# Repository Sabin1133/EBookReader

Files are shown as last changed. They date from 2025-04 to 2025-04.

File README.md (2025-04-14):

###### Copyright Sabin Padurariu 2025

# OpenBook E-Reader

## General Overview

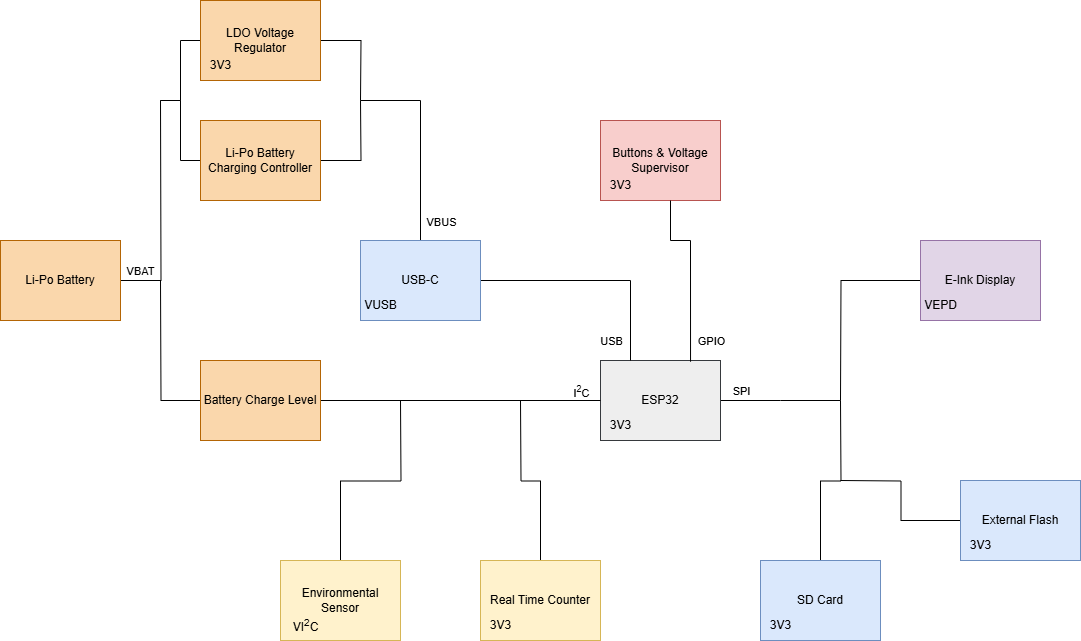
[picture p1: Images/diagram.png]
diagram


OpenBook is a compact electronic device designed around the ESP32 microcontroller. This device integrates several key features, including:

* Li-Po battery charging and power management
* E-Paper display for visual output
* Environmental sensing capabilities with the BME688 sensor
* Real-Time Clock (RTC) functionality using the DS3231SN
* SD Card slot for data storage
* External NOR Flash memory
* USB-C connectivity

## Bill of Materials

| Name | Price Link | Datasheet Link |
|---|---|---|
|	BOOT_BUTTON	|	https://www.snapeda.com/parts/EVQP7L01P/Panasonic/view-part/?welcome=home&ref=search&t=evqp7l01p	|	https://industry.panasonic.com/global/en/downloads?tab=catalog&small_g_cd=203&part_no=EVQPUJ02K	|
|	C1	|	https://componentsearchengine.com/part-view/CC0402MRX5R5BB106/YAGEO	|	https://componentsearchengine.com/Datasheets/2/CC0402MRX5R5BB106.pdf	|
|	C1_BAT	|	https://componentsearchengine.com/part-view/CC0402MRX5R5BB106/YAGEO	|	https://componentsearchengine.com/Datasheets/2/CC0402MRX5R5BB106.pdf	|
|	C1_BAT1	|	https://www.snapeda.com/parts/CC0402DRNPO9BN5R1/Yageo/view-part/?ref=dk&t=LTSPICE_CC0402&con_ref=None	|	https://s3.amazonaws.com/snapeda/datasheet/CC0402DRNPO9BN5R1_Yageo.pdf	|
|	C2_BAT1	|	https://www.snapeda.com/parts/CC0402DRNPO9BN5R1/Yageo/view-part/?ref=dk&t=LTSPICE_CC0402&con_ref=None	|	https://s3.amazonaws.com/snapeda/datasheet/CC0402DRNPO9BN5R1_Yageo.pdf	|
|	C1_BAT2	| https://www.snapeda.com/parts/CC0402DRNPO9BN5R1/Yageo/view-part/?ref=dk&t=LTSPICE_CC0402&con_ref=None	|	https://s3.amazonaws.com/snapeda/datasheet/CC0402DRNPO9BN5R1_Yageo.pdf	|
|	C2	|	https://componentsearchengine.com/part-view/CC0402MRX5R5BB106/YAGEO	|	https://componentsearchengine.com/Datasheets/2/CC0402MRX5R5BB106.pdf	|
|	C2_BAT	|	https://componentsearchengine.com/part-view/CC0402MRX5R5BB106/YAGEO	|	https://componentsearchengine.com/Datasheets/2/CC0402MRX5R5BB106.pdf	|
|	C3	|	https://componentsearchengine.com/part-view/T491B107M006AT/KEMET	|	https://s3.amazonaws.com/snapeda/datasheet/TAJB475K025RNJ_AVX.pdf	|
|	C4	|	https://componentsearchengine.com/part-view/CC0402MRX5R5BB106/YAGEO	|	https://componentsearchengine.com/Datasheets/2/CC0402MRX5R5BB106.pdf	|
|	C4_USB	|	https://componentsearchengine.com/part-view/CC0402MRX5R5BB106/YAGEO	|	https://componentsearchengine.com/Datasheets/2/CC0402MRX5R5BB106.pdf	|
|	C5	|	https://componentsearchengine.com/part-view/CC0402MRX5R5BB106/YAGEO	|	https://componentsearchengine.com/Datasheets/2/CC0402MRX5R5BB106.pdf	|
|	C5_USB	|	https://componentsearchengine.com/part-view/CC0402MRX5R5BB106/YAGEO	|	https://componentsearchengine.com/Datasheets/2/CC0402MRX5R5BB106.pdf	|
|	C6	|	https://componentsearchengine.com/part-view/CC0402MRX5R5BB106/YAGEO	|	https://componentsearchengine.com/Datasheets/2/CC0402MRX5R5BB106.pdf	|
|	C7	|	https://componentsearchengine.com/part-view/CC0402MRX5R5BB106/YAGEO	|	https://componentsearchengine.com/Datasheets/2/CC0402MRX5R5BB106.pdf	|
|	C8	|	https://componentsearchengine.com/part-view/CC0402MRX5R5BB106/YAGEO	|	https://componentsearchengine.com/Datasheets/2/CC0402MRX5R5BB106.pdf	|
|	C9	|	https://www.snapeda.com/parts/CC0402DRNPO9BN5R1/Yageo/view-part/?ref=dk&t=LTSPICE_CC0402&con_ref=None	|	https://s3.amazonaws.com/snapeda/datasheet/CC0402DRNPO9BN5R1_Yageo.pdf	|
|	C10	|	https://componentsearchengine.com/part-view/CC0402MRX5R5BB106/YAGEO	|	https://componentsearchengine.com/Datasheets/2/CC0402MRX5R5BB106.pdf	|
|	C10_SUPERCAP	|	https://www.snapeda.com/parts/CPH3225A/Seiko+Instruments/view-part/?ref=eda	|	https://www.snapeda.com/parts/CPH3225A/Seiko%20Instruments/datasheet/	|
|	CHANGE_BUTTON	|	https://www.snapeda.com/parts/EVQP7L01P/Panasonic/view-part/?welcome=home&ref=search&t=evqp7l01p	|	https://industry.panasonic.com/global/en/downloads?tab=catalog&small_g_cd=203&part_no=EVQPUJ02K	|
|	CHG_LED	|	https://www.snapeda.com/parts/KP-1608SURCK/Kingbright/view-part/?ref=search&t=LED%200603	|	https://www.snapeda.com/parts/KP-1608SURCK/Kingbright/datasheet/	|
|	C_DELAY	|	https://componentsearchengine.com/part-view/CC0402MRX5R5BB106/YAGEO	|	https://componentsearchengine.com/Datasheets/2/CC0402MRX5R5BB106.pdf	|
|	D1	|	https://www.snapeda.com/parts/USBLC6-2SC6Y/STMicroelectronics/view-part/?ref=snap	|	https://www.snapeda.com/parts/USBLC6-2SC6Y/STMicroelectronics/datasheet/	|
|	D2	|	https://ro.mouser.com/ProductDetail/KYOCERA-AVX/SD0805S020S1R0?qs=jCA%252BPfw4LHbpkAoSnwrdjw%3D%3D	|	http://datasheets.avx.com/schottky.pdf	|
|	D3	|	https://www.snapeda.com/parts/MBR0530/Onsemi/view-part/?ref=eda	|	https://www.snapeda.com/parts/MBR0530/ON%20Semiconductor/datasheet/	|
|	D4	|	https://www.snapeda.com/parts/MBR0530/Onsemi/view-part/?ref=eda	|	https://www.snapeda.com/parts/MBR0530/ON%20Semiconductor/datasheet/	|
|	D5	|	https://www.snapeda.com/parts/MBR0530/Onsemi/view-part/?ref=eda	|	https://www.snapeda.com/parts/MBR0530/ON%20Semiconductor/datasheet/	|
|	D6	|	https://www.snapeda.com/parts/PGB1010603MR/Littelfuse/view-part/?ref=eda	|	https://www.snapeda.com/parts/PGB1010603MR/Littelfuse%20Inc./datasheet/	|
|	D7	|	https://ro.mouser.com/ProductDetail/KYOCERA-AVX/SD0805S020S1R0?qs=jCA%252BPfw4LHbpkAoSnwrdjw%3D%3D	|	http://datasheets.avx.com/schottky.pdf	|
|	D8	|	https://www.snapeda.com/parts/PGB1010603MR/Littelfuse/view-part/?ref=eda	|	https://www.snapeda.com/parts/PGB1010603MR/Littelfuse%20Inc./datasheet/	|
|	D9	|	https://www.snapeda.com/parts/PGB1010603MR/Littelfuse/view-part/?ref=eda	|	https://www.snapeda.com/parts/PGB1010603MR/Littelfuse%20Inc./datasheet/	|
|	D10	|	https://www.snapeda.com/parts/PGB1010603MR/Littelfuse/view-part/?ref=eda	|	https://www.snapeda.com/parts/PGB1010603MR/Littelfuse%20Inc./datasheet/	|
|	D11	|	https://www.snapeda.com/parts/PGB1010603MR/Littelfuse/view-part/?ref=eda	|	https://www.snapeda.com/parts/PGB1010603MR/Littelfuse%20Inc./datasheet/	|
|	D12	|	https://www.snapeda.com/parts/PGB1010603MR/Littelfuse/view-part/?ref=eda	|	https://www.snapeda.com/parts/PGB1010603MR/Littelfuse%20Inc./datasheet/	|
|	EPD_C1	|	https://componentsearchengine.com/part-view/CC0402MRX5R5BB106/YAGEO	|	https://componentsearchengine.com/Datasheets/2/CC0402MRX5R5BB106.pdf	|
|	EPD_C2	|	https://componentsearchengine.com/part-view/CC0402MRX5R5BB106/YAGEO	|	https://componentsearchengine.com/Datasheets/2/CC0402MRX5R5BB106.pdf	|
|	EPD_C5	|	https://componentsearchengine.com/part-view/CC0402MRX5R5BB106/YAGEO	|	https://componentsearchengine.com/Datasheets/2/CC0402MRX5R5BB106.pdf	|
|	EPD_C6	|	https://componentsearchengine.com/part-view/CC0402MRX5R5BB106/YAGEO	|	https://componentsearchengine.com/Datasheets/2/CC0402MRX5R5BB106.pdf	|
|	EPD_C7	|	https://componentsearchengine.com/part-view/CC0402MRX5R5BB106/YAGEO	|	https://componentsearchengine.com/Datasheets/2/CC0402MRX5R5BB106.pdf	|
|	EPD_C8	|	https://componentsearchengine.com/part-view/CC0402MRX5R5BB106/YAGEO	|	https://componentsearchengine.com/Datasheets/2/CC0402MRX5R5BB106.pdf	|
|	EPD_C9	|	https://componentsearchengine.com/part-view/CC0402MRX5R5BB106/YAGEO	|	https://componentsearchengine.com/Datasheets/2/CC0402MRX5R5BB106.pdf	|
|	EPD_C10	|	https://componentsearchengine.com/part-view/CC0402MRX5R5BB106/YAGEO	|	https://componentsearchengine.com/Datasheets/2/CC0402MRX5R5BB106.pdf	|
|	EPD_C11	|	https://componentsearchengine.com/part-view/CC0402MRX5R5BB106/YAGEO	|	https://componentsearchengine.com/Datasheets/2/CC0402MRX5R5BB106.pdf	|
|	EPD_C12	|	https://componentsearchengine.com/part-view/CC0402MRX5R5BB106/YAGEO	|	https://componentsearchengine.com/Datasheets/2/CC0402MRX5R5BB106.pdf	|
|	IC1	|	https://componentsearchengine.com/part-view/BD5229G-TR/ROHM%20Semiconductor	|	https://datasheet.datasheetarchive.com/originals/distributors/Datasheets_SAMA/f2b9741ef86007909f138d561a359946.pdf	|
|	IC4	|	https://componentsearchengine.com/part-view/XC6220A331MR-G/Torex	|	https://product.torexsemi.com/system/files/series/xc6220.pdf	|
|	J1	|	https://componentsearchengine.com/part-view/FH34SRJ-24S-0.5SH(99)/Hirose	|	https://www.hirose.com/en/product/document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	|
|	J2	|	https://componentsearchengine.com/part-view/USB4110-GF-A/GCT%20(GLOBAL%20CONNECTOR%20TECHNOLOGY)	|	https://gct.co/files/drawings/usb4110.pdf	|
|	J3	|	https://componentsearchengine.com/part-view/SM04B-SRSS-TB(LF)(SN)/JST%20(JAPAN%20SOLDERLESS%20TERMINALS)	| - |
|	J4	|	https://store.comet.srl.ro/Catalogue/Product/43497/	|	https://store.comet.srl.ro/Catalogue/Product/43497/	|
|	L1	|	https://ro.mouser.com/ProductDetail/Wurth-Elektronik/744043680?qs=PGXP4M47uW6VkZq%252BkzjrHA%3D%3D	|	https://www.we-online.com/components/products/datasheet/744043680.pdf	|
|	PFMF.050.1	|	https://ro.mouser.com/ProductDetail/EPCOS-TDK/B72520T0350K062?qs=dEfas%2FXlABIszF52uu7vrg%3D%3D	|	https://www.mouser.co.uk/ProductDetail/EPCOS-TDK/B72520T0350K062?qs=dEfas%2FXlABIszF52uu7vrg%3D%3D	|
|	Q1	|	https://componentsearchengine.com/part-view/DMG2305UX-7/Diodes%20Incorporated	|	https://www.diodes.com//assets/Datasheets/DMG2305UX.pdf	|
|	Q2	|	https://componentsearchengine.com/part-view/DMG2305UX-7/Diodes%20Incorporated	|	https://www.diodes.com//assets/Datasheets/DMG2305UX.pdf	|
|	Q3	|	https://componentsearchengine.com/part-view/SI1308EDL-T1-GE3/Vishay	|	https://componentsearchengine.com/Datasheets/1/SI1308EDL-T1-GE3.pdf	|
|	R1	|	https://componentsearchengine.com/part-view/R0402%201%25%20100%20K%20(RC0402FR-07100KL)/YAGEO	|	https://www.yageo.com/upload/media/product/products/datasheet/rchip/PYu-RC_Group_51_RoHS_L_12.pdf	|
|	R1-PINH	|	https://componentsearchengine.com/part-view/R0402%201%25%20100%20K%20(RC0402FR-07100KL)/YAGEO	|	https://www.yageo.com/upload/media/product/products/datasheet/rchip/PYu-RC_Group_51_RoHS_L_12.pdf	|
|	R1-PINH1	|	https://componentsearchengine.com/part-view/R0402%201%25%20100%20K%20(RC0402FR-07100KL)/YAGEO	|	https://www.yageo.com/upload/media/product/products/datasheet/rchip/PYu-RC_Group_51_RoHS_L_12.pdf	|
|	R1_BAT	|	https://componentsearchengine.com/part-view/R0402%201%25%20100%20K%20(RC0402FR-07100KL)/YAGEO	|	https://www.yageo.com/upload/media/product/products/datasheet/rchip/PYu-RC_Group_51_RoHS_L_12.pdf	|
|	R1_PWRUSB	|	https://componentsearchengine.com/part-view/R0402%201%25%20100%20K%20(RC0402FR-07100KL)/YAGEO	|	https://www.yageo.com/upload/media/product/products/datasheet/rchip/PYu-RC_Group_51_RoHS_L_12.pdf	|
|	R2	|	https://componentsearchengine.com/part-view/R0402%201%25%20100%20K%20(RC0402FR-07100KL)/YAGEO	|	https://www.yageo.com/upload/media/product/products/datasheet/rchip/PYu-RC_Group_51_RoHS_L_12.pdf	|
|	R2-PINH	|	https://componentsearchengine.com/part-view/R0402%201%25%20100%20K%20(RC0402FR-07100KL)/YAGEO	|	https://www.yageo.com/upload/media/product/products/datasheet/rchip/PYu-RC_Group_51_RoHS_L_12.pdf	|
|	R2-PINH1	|	https://componentsearchengine.com/part-view/R0402%201%25%20100%20K%20(RC0402FR-07100KL)/YAGEO	|	https://www.yageo.com/upload/media/product/products/datasheet/rchip/PYu-RC_Group_51_RoHS_L_12.pdf	|
|	R2-USB	|	https://componentsearchengine.com/part-view/R0402%201%25%20100%20K%20(RC0402FR-07100KL)/YAGEO	|	https://www.yageo.com/upload/media/product/products/datasheet/rchip/PYu-RC_Group_51_RoHS_L_12.pdf	|
|	R2-USB1	|	https://componentsearchengine.com/part-view/R0402%201%25%20100%20K%20(RC0402FR-07100KL)/YAGEO	|	https://www.yageo.com/upload/media/product/products/datasheet/rchip/PYu-RC_Group_51_RoHS_L_12.pdf	|
|	R2_BAT	|	https://componentsearchengine.com/part-view/R0402%201%25%20100%20K%20(RC0402FR-07100KL)/YAGEO	|	https://www.yageo.com/upload/media/product/products/datasheet/rchip/PYu-RC_Group_51_RoHS_L_12.pdf	|
|	R3	|	https://componentsearchengine.com/part-view/R0402%201%25%20100%20K%20(RC0402FR-07100KL)/YAGEO	|	https://www.yageo.com/upload/media/product/products/datasheet/rchip/PYu-RC_Group_51_RoHS_L_12.pdf	|
|	R4	|	https://componentsearchengine.com/part-view/R0402%201%25%20100%20K%20(RC0402FR-07100KL)/YAGEO	|	https://www.yageo.com/upload/media/product/products/datasheet/rchip/PYu-RC_Group_51_RoHS_L_12.pdf	|
|	R5	|	https://componentsearchengine.com/part-view/R0402%201%25%20100%20K%20(RC0402FR-07100KL)/YAGEO	|	https://www.yageo.com/upload/media/product/products/datasheet/rchip/PYu-RC_Group_51_RoHS_L_12.pdf	|
|	R6	|	https://componentsearchengine.com/part-view/R0402%201%25%20100%20K%20(RC0402FR-07100KL)/YAGEO	|	https://www.yageo.com/upload/media/product/products/datasheet/rchip/PYu-RC_Group_51_RoHS_L_12.pdf	|
|	R7	|	https://componentsearchengine.com/part-view/R0402%201%25%20100%20K%20(RC0402FR-07100KL)/YAGEO	|	https://www.yageo.com/upload/media/product/products/datasheet/rchip/PYu-RC_Group_51_RoHS_L_12.pdf	|
|	R8	|	https://componentsearchengine.com/part-view/R0402%201%25%20100%20K%20(RC0402FR-07100KL)/YAGEO	|	https://www.yageo.com/upload/media/product/products/datasheet/rchip/PYu-RC_Group_51_RoHS_L_12.pdf	|
|	R9	|	https://componentsearchengine.com/part-view/R0402%201%25%20100%20K%20(RC0402FR-07100KL)/YAGEO	|	https://www.yageo.com/upload/media/product/products/datasheet/rchip/PYu-RC_Group_51_RoHS_L_12.pdf	|
|	R10	|	https://componentsearchengine.com/part-view/R0402%201%25%20100%20K%20(RC0402FR-07100KL)/YAGEO	|	https://www.yageo.com/upload/media/product/products/datasheet/rchip/PYu-RC_Group_51_RoHS_L_12.pdf	|
|	RESET_BUTTON	|	https://www.snapeda.com/parts/EVQP7L01P/Panasonic/view-part/?welcome=home&ref=search&t=evqp7l01p	|	https://industry.panasonic.com/global/en/downloads?tab=catalog&small_g_cd=203&part_no=EVQPUJ02K	|
|	R_BOOT	|	https://componentsearchengine.com/part-view/R0402%201%25%20100%20K%20(RC0402FR-07100KL)/YAGEO	|	https://www.yageo.com/upload/media/product/products/datasheet/rchip/PYu-RC_Group_51_RoHS_L_12.pdf	|
|	R_CAPACITOR	|	https://componentsearchengine.com/part-view/R0402%201%25%20100%20K%20(RC0402FR-07100KL)/YAGEO	|	https://www.yageo.com/upload/media/product/products/datasheet/rchip/PYu-RC_Group_51_RoHS_L_12.pdf	|
|	R_CHANGE	|	https://componentsearchengine.com/part-view/R0402%201%25%20100%20K%20(RC0402FR-07100KL)/YAGEO	|	https://www.yageo.com/upload/media/product/products/datasheet/rchip/PYu-RC_Group_51_RoHS_L_12.pdf	|
|	R_CL1	|	https://componentsearchengine.com/part-view/R0402%201%25%20100%20K%20(RC0402FR-07100KL)/YAGEO	|	https://www.yageo.com/upload/media/product/products/datasheet/rchip/PYu-RC_Group_51_RoHS_L_12.pdf	|
|	R_RESET	|	https://componentsearchengine.com/part-view/R0402%201%25%20100%20K%20(RC0402FR-07100KL)/YAGEO	|	https://www.yageo.com/upload/media/product/products/datasheet/rchip/PYu-RC_Group_51_RoHS_L_12.pdf	|
|	SENSOR2	|	https://www.snapeda.com/parts/BME680/Bosch/view-part/?welcome=home	|	https://www.snapeda.com/parts/BME680/Bosch%20Sensortec/datasheet/	|
|	SJ1	|	https://grabcad.com/library/solder-jumpers-1	|	https://www.digikey.com/en/htmldatasheets/production/1809569/0/0/1/jumpers	|
|	U1	|	https://www.snapeda.com/parts/W25Q512JVEIQ/Winbond+Electronics/view-part/?ref=eda	|	https://www.snapeda.com/parts/W25Q512JVEIQ/Winbond%20Electronics/datasheet/	|
|	U2	|	https://www.snapeda.com/parts/ESP32-C6-WROOM-1-N8/Espressif+Systems/view-part/?ref=eda	|	https://www.snapeda.com/parts/ESP32-C6-WROOM-1-N8/Espressif%20Systems/datasheet/	|
|	U3	|	https://www.snapeda.com/parts/DS3231SN%23/Analog%20Devices/view-part/?ref=dk&t=DS3231SN%23&con_ref=None	|	https://www.snapeda.com/parts/DS3231SN%23/Analog%20Devices/datasheet/	|
|	U4	|	https://www.snapeda.com/parts/MAX17048G+T10/Analog+Devices/view-part/?ref=eda	|	https://www.snapeda.com/parts/MAX17048G+T10/Analog%20Devices/datasheet/	|
|	U5	|	https://ro.mouser.com/ProductDetail/Microchip-Technology/MCP73831T-2ACI-OT?qs=yUQqVecv4qvbBQBGbHx0Mw%3D%3D	|	https://ro.mouser.com/datasheet/2/268/MCP73831_Family_Data_Sheet_DS20001984H-3441711.pdf	|

## Functionality

The schematic highlights the interconnection of these components, with the ESP32 acting as the central processing unit, coordinating data acquisition, processing, and display.

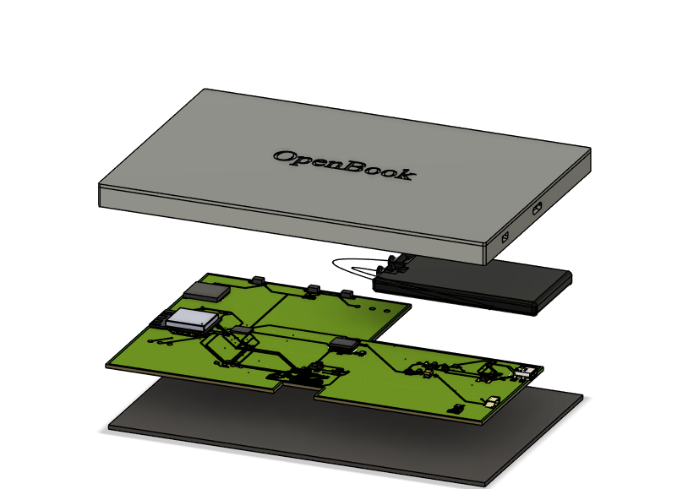
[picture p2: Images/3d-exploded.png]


## Modules

At its core, Openbook consists of five main modules:

* Power and battery module
* Processing module
* General Devices Module
* I/O Devices Module
* Display Module

### Processing and Calculations

The ESP32 processes data from the sensors and controls the RGB LED module. Calculations are performed to convert the raw sensor data into relevant units of measurement.

Power consumption calculations:

* ESP32 in active mode consumes around 5mA
* ESP32 in sleep mode consumes around 5µA
* The temperature and humidity sensor consume approximately 2.5mA

Battery life estimations:

* in normal mode expected lifetime is about 12 weeks
* in performance mode expected lifetime is about 6 weeks

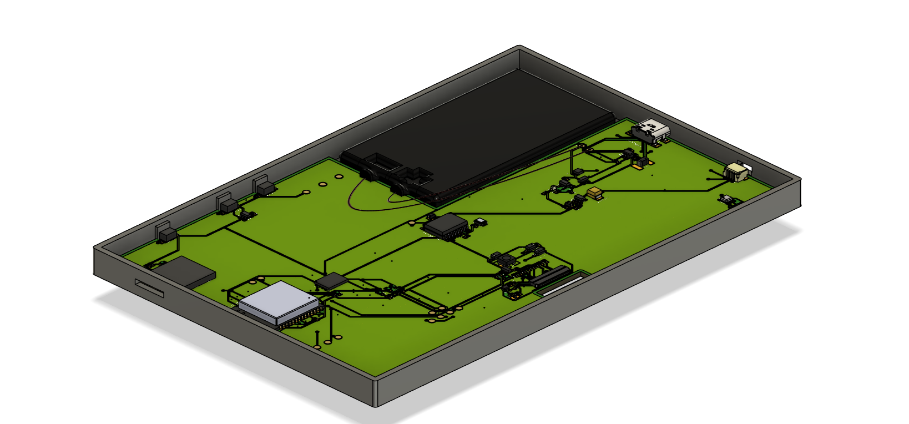
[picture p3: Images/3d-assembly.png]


### ESP32 GPIO

The ESP32-C6 utilizes its General Purpose Input/Output (GPIO) pins to interface with various peripherals.  Based on the schematic, here are some notable GPIO connections:

* **E-Paper Display:** The ESP32 communicates with the E-Paper display via several GPIOs through the FFC connector. These GPIOs are responsible for transmitting data and control signals to update the display.
* **SD Card:** GPIOs are dedicated to the SD Card interface, enabling the ESP32 to read from and write data to the SD card.
* **BME688 Sensor:** The ESP32 communicates with the BME688 environmental sensor using GPIOs for data transfer and control.
* **RTC Module (DS3231SN):** GPIOs are used to communicate with the DS3231SN RTC module to maintain accurate timekeeping.
* **Control Buttons:** GPIOs are connected to the Reset and Boot buttons, allowing user interaction and device control.

### SPI and I2C Communication Protocols

The ESP32-C6 employs both SPI and I2C serial communication protocols to interact with peripherals:

* **SPI (Serial Peripheral Interface):** SPI is a synchronous serial communication interface used for short-distance communication, particularly in embedded systems.  In this design, SPI is likely used to communicate with the **external NOR Flash memory** and the **SD Card**. SPI involves a master-slave architecture with dedicated lines for:
    * **SCK (Serial Clock):** Provides the clock signal for synchronization
    * **MOSI (Master Out Slave In):** Data line from the master to the slave
    * **MISO (Master In Slave Out):** Data line from the slave to the master
    * **CS (Chip Select):** Used by the master to select a specific slave device

* **I2C (Inter-Integrated Circuit):** I2C is another serial communication protocol that uses only two wires:
    * **SDA (Serial Data):** Carries the data
    * **SCL (Serial Clock):** Carries the clock signal

I2C is used for communication with the **RTC module** and the **Environmental sensor** as seen in the schematic. I2C supports multiple devices on the same bus using addressing, making it suitable for communicating with several slower peripherals.

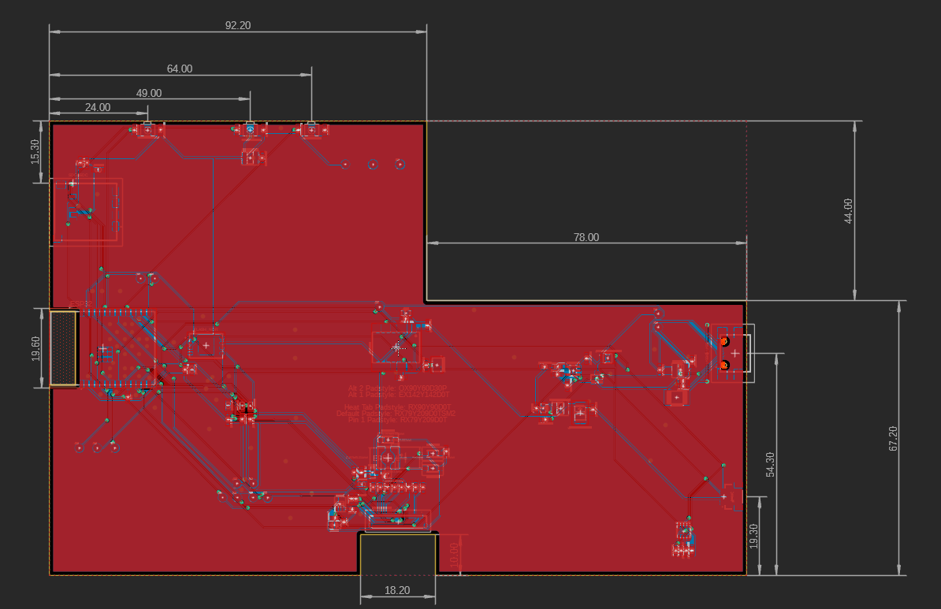
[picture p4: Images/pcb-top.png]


## Implementation Problems

### USB Vusb Pin

The Power Pin VUSB had problems when it came to be routed primarily because
of the placement of the component but also because of the placement of the pins
of the components on the PCB.

The solution was to just add a via that connected the Top and Bottom layers and
route the connection using that path. Even though not advisable it was the only
way possible.

#### Before

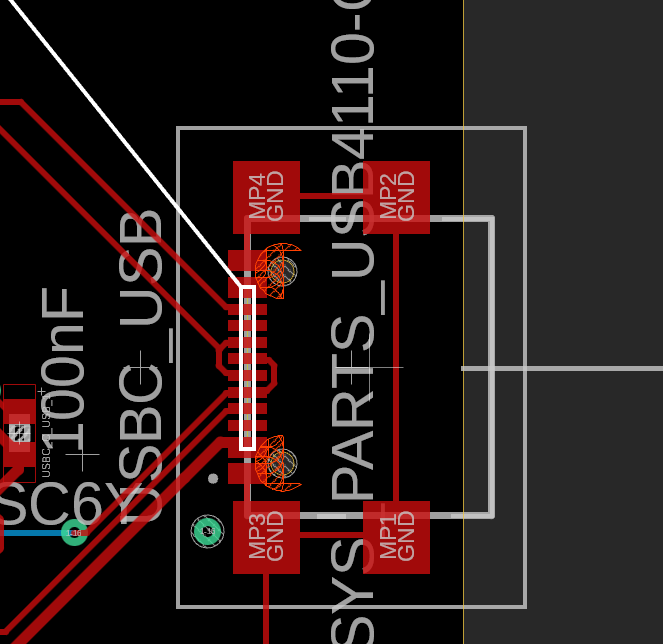
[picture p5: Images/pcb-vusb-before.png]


#### After

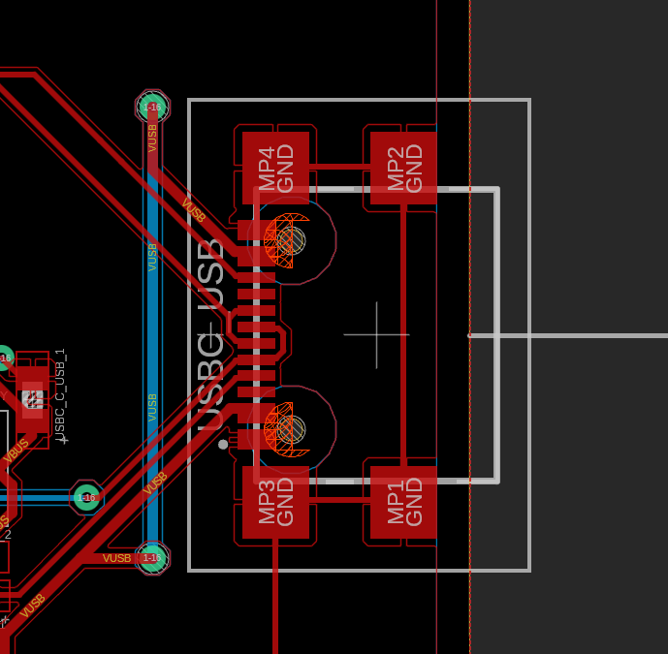
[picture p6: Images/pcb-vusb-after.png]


### SD Card Placement

The placement of the SD Card was a bit off at first due to the placement of the
pins on the PCB but also due to the fact that the enclosure's was missaligned.

In order to preserve the required specification and the design of the entire
PCB, the solution was to gently shift the component until the holes aligned
properly and ensured a proper connection between both ends.

#### Before

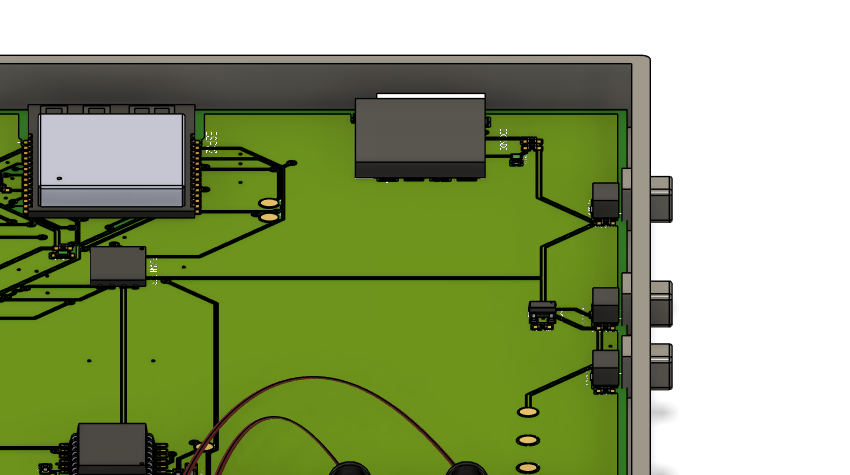
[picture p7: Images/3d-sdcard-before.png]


#### After

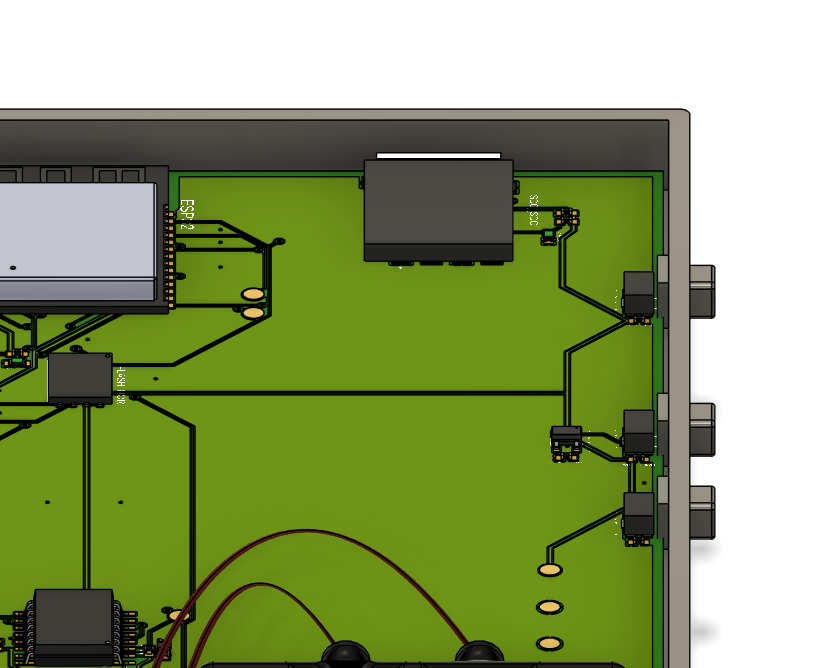
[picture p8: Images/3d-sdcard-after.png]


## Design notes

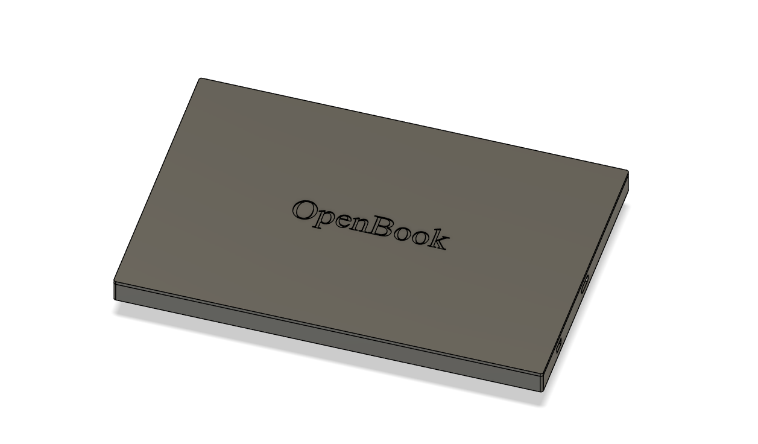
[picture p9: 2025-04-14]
Images/3d-overview.png

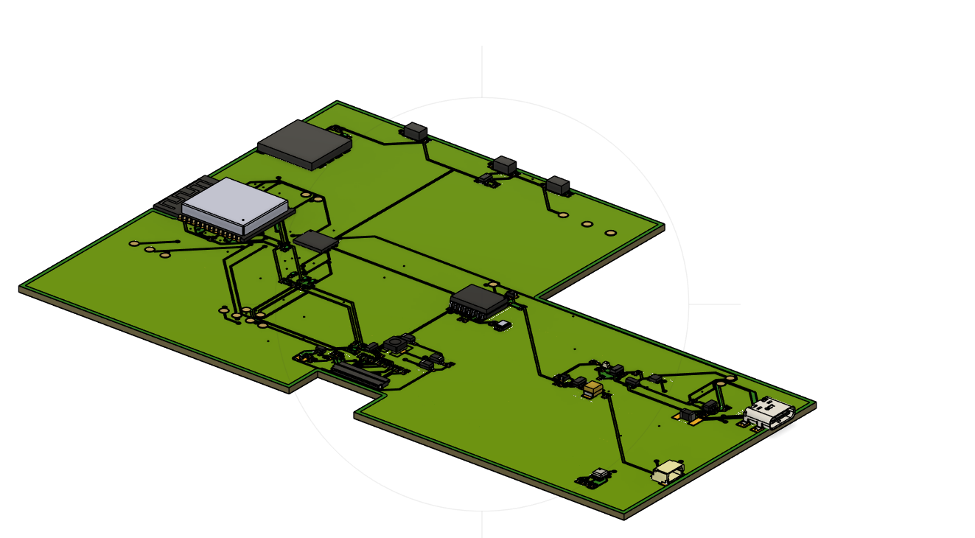
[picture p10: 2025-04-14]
Images/3d-pcb-overview.png

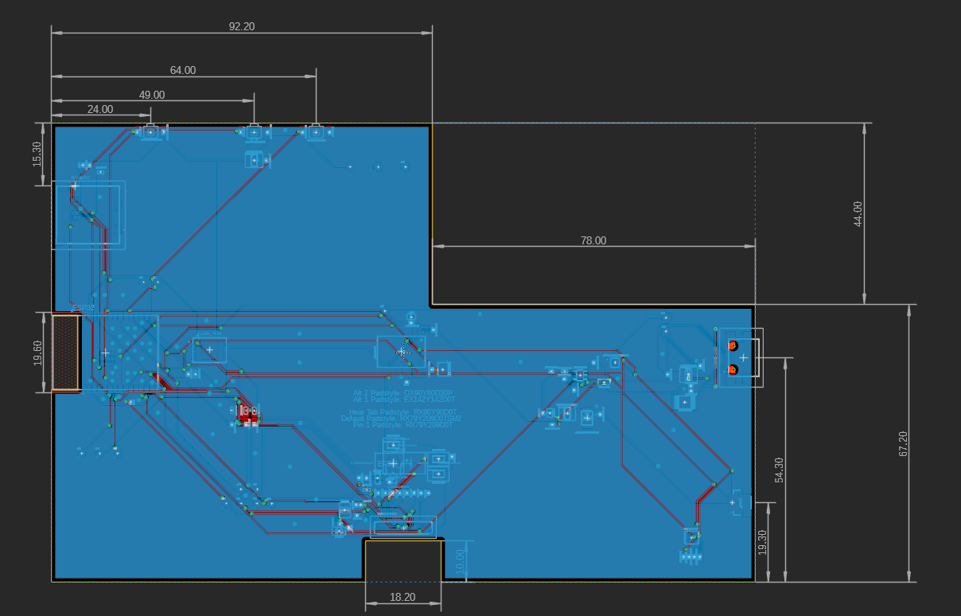
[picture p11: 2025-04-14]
Images/pcb-bottom.png

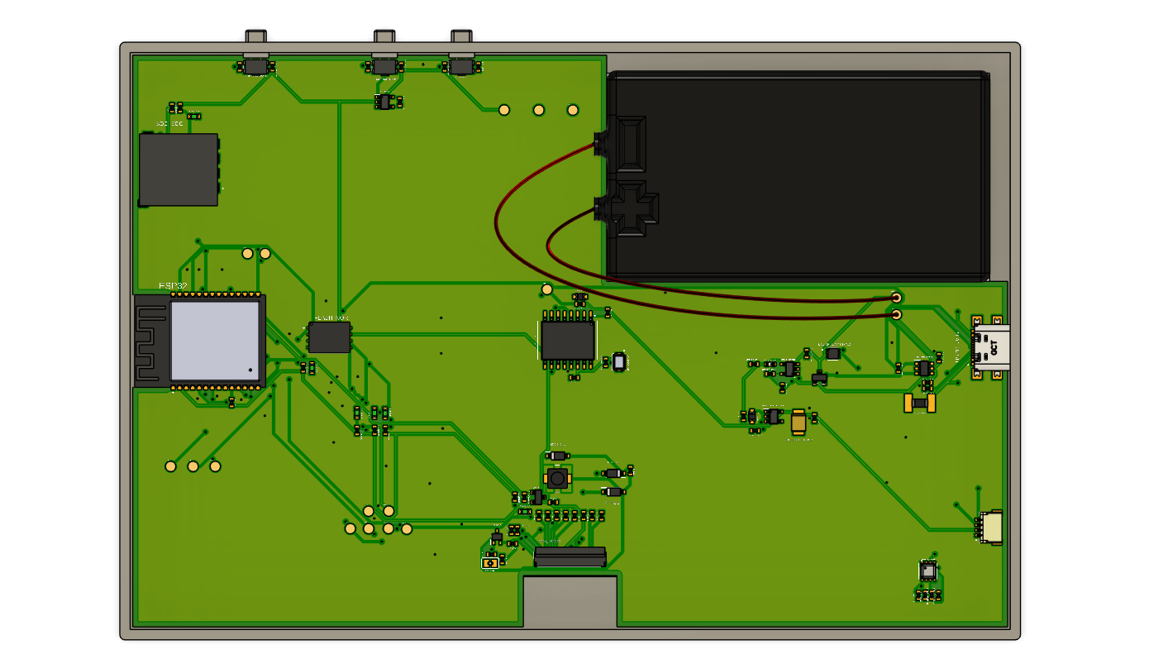
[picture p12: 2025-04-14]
Images/3d-pcb-top.png

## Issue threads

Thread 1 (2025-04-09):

Air Wire Error

mtimaN, 2025-04-09:
The USB-C Port seems to have 2 unrouted wires.

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

Let me know if the issue is reproducible on your end.

Closed 2025-04-11.

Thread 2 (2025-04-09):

Silkscreen visibility issue

mtimaN, 2025-04-09:
Silkscreen is obstructed by 3D piece for "EPD_C*". See image below:

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

Other silkscreen issues also appear around the QWIIC connector.
Let me know if you need any help solving it.

Closed 2025-04-11.

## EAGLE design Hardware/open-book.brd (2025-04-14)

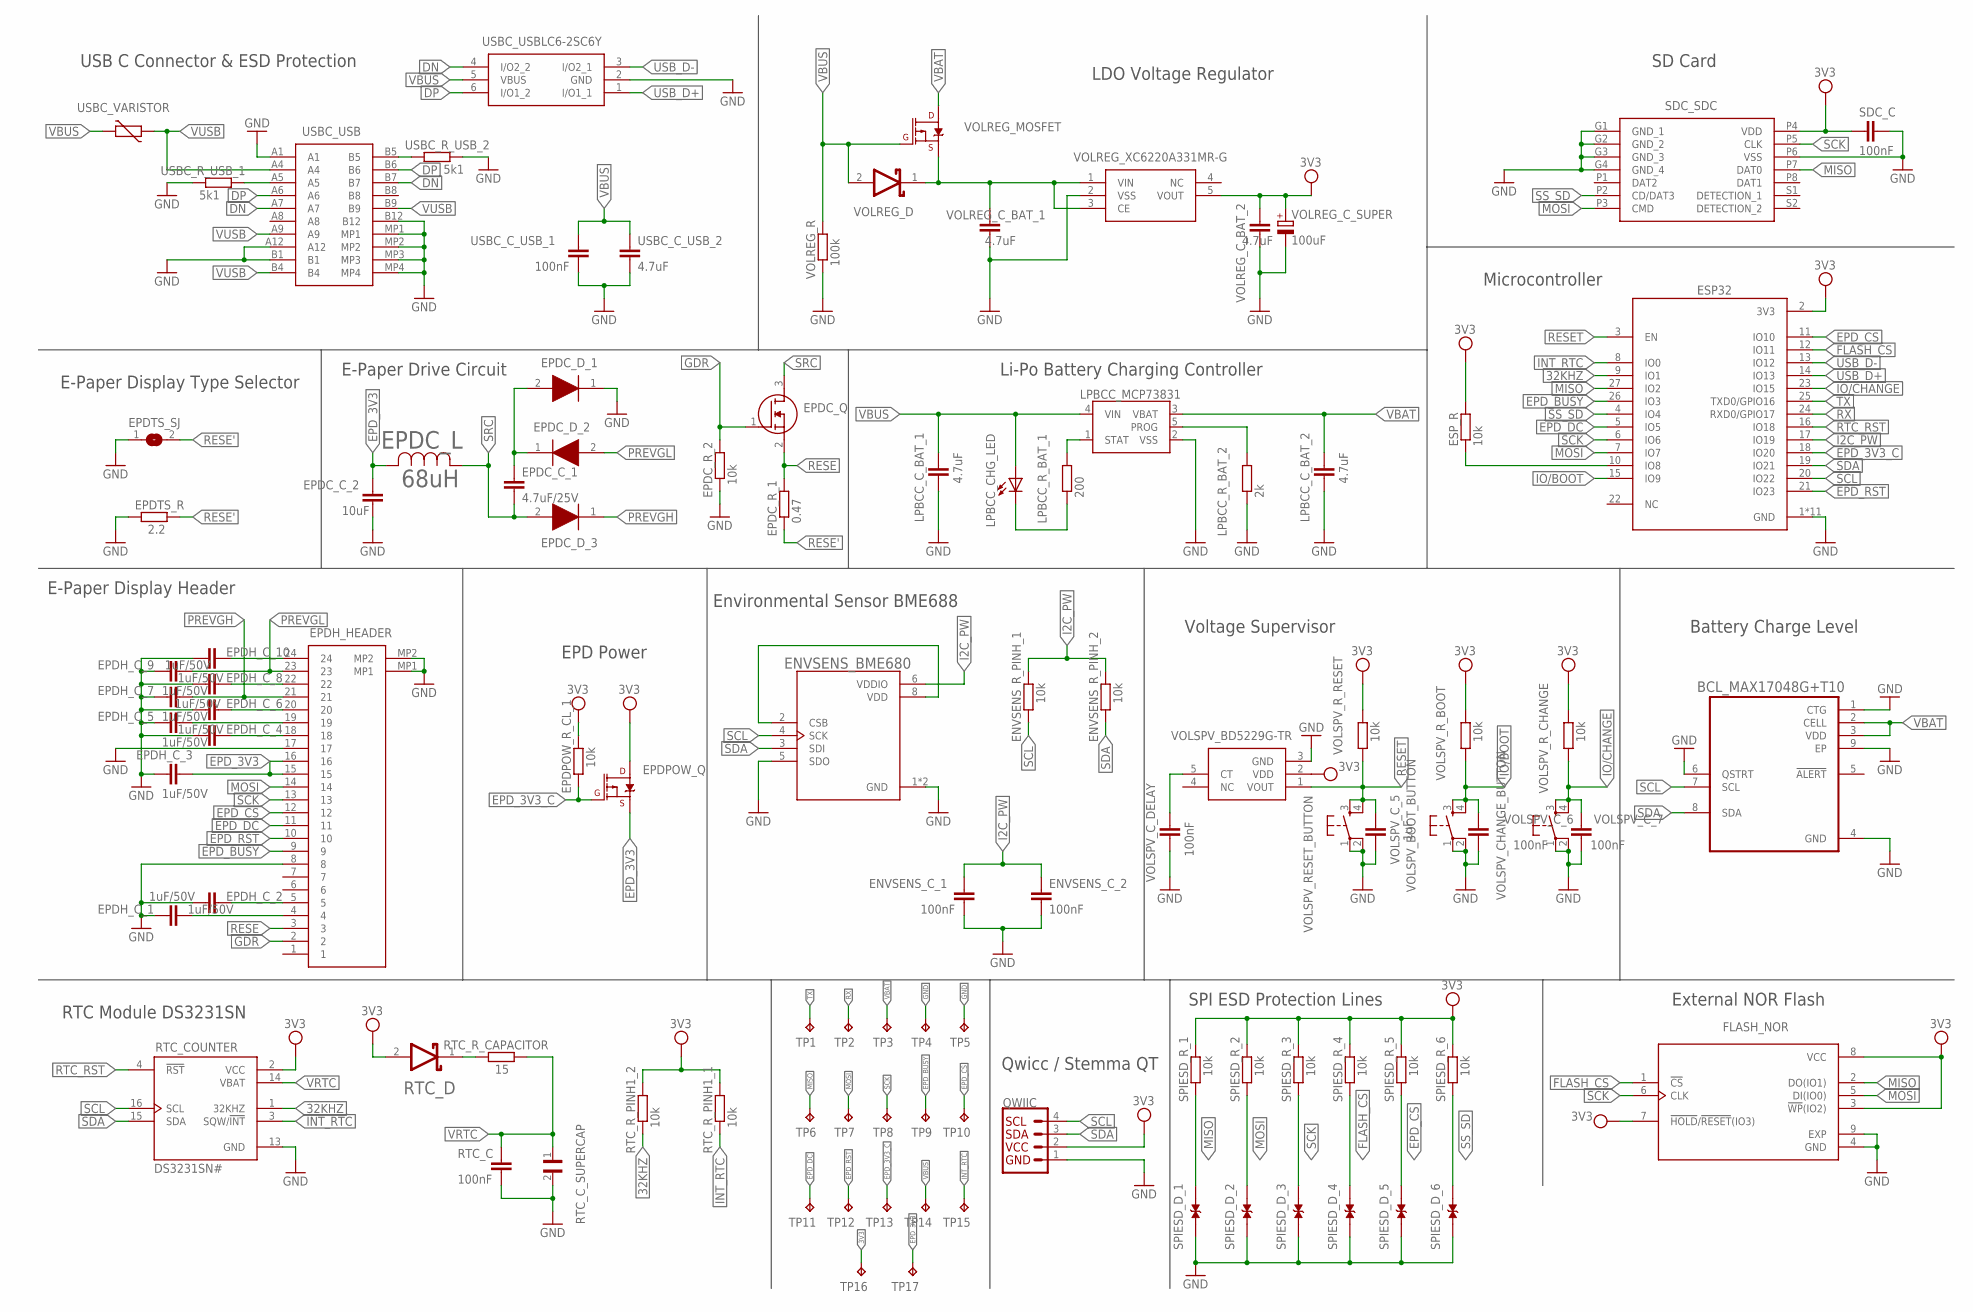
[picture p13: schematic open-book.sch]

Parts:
BCL_MAX17048G+T10: MAX17048G+T10; SON50P200X200X80-9N
ENVSENS_BME680: ESP32_WROVER_BME680_BME680; ESP32_WROVER_BME680_PSON80P300X300X100-8N
ENVSENS_C_1, ENVSENS_C_2: 100nF; EAGLE-LTSPICE_C0402
ENVSENS_R_PINH_1, ENVSENS_R_PINH_2: 10k; ESP32_WROVER_EAGLE-LTSPICE_R0402
EPDC_C_1: 4.7uF/25V; EAGLE-LTSPICE_C0402
EPDC_C_2: 10uF; EAGLE-LTSPICE_C0402
EPDC_D_1, EPDC_D_2, EPDC_D_3: MBR0530; SOD3716X135N
EPDC_L: 68uH; IND_4828-WE-TPC_WRE
EPDC_Q: SI1308EDL-T1-GE3; SOT65P210X110-3N
EPDC_R_1: 0.47; ESP32_WROVER_EAGLE-LTSPICE_R0402
EPDC_R_2: 10k; ESP32_WROVER_EAGLE-LTSPICE_R0402
EPDH_C_1, EPDH_C_2, EPDH_C_3, EPDH_C_4, EPDH_C_5, EPDH_C_6, EPDH_C_7, EPDH_C_8, EPDH_C_9, EPDH_C_10: 1uF/50V; EAGLE-LTSPICE_C0402
EPDH_HEADER: FH34SRJ-24S-0.5SH_99_; FH34SRJ24S05SH99
EPDPOW_Q: 20V/4.2A/52mΩ/1.4W; ESP32_WROVER_SPARKFUN-DISCRETESEMI_SOT23-3
EPDPOW_R_CL_1: 10k; ESP32_WROVER_EAGLE-LTSPICE_R0402
EPDTS_R: 2.2; ESP32_WROVER_EAGLE-LTSPICE_R0402
EPDTS_SJ: SJ
ESP32: ESP32-C6-WROOM-1-N8; XCVR_ESP32-C6-WROOM-1-N8
ESP_R: 10k; ESP32_WROVER_EAGLE-LTSPICE_R0402
FLASH_NOR: W25Q512JVEIQ; SON127P600X800X80-9N
LPBCC_CHG_LED: ADAFRUIT_LED; ADAFRUIT_CHIP-LED0603
LPBCC_C_BAT_1, LPBCC_C_BAT_2: 4.7uF; EAGLE-LTSPICE_C0402
LPBCC_MCP73831: ESP32_WROVER_SPARKFUN-IC-POWER_MCP73831; ESP32_WROVER_SPARKFUN-IC-POWER_SOT23-5
LPBCC_R_BAT_1: 200; ESP32_WROVER_EAGLE-LTSPICE_R0402
LPBCC_R_BAT_2: 2k; ESP32_WROVER_EAGLE-LTSPICE_R0402
QWIIC: QWIIC_RIGHT_ANGLE; JST04_1MM_RA
RTC_C: 100nF; EAGLE-LTSPICE_C0402
RTC_COUNTER: DS3231SN#; SOIC127P1032X265-16N
RTC_C_SUPERCAP: CPH3225A; CAPCP3225X100N
RTC_D: ESP32_WROVER_AVX---SD0805S020S1R0_AVX_SD0805S020S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; ESP32_WROVER_AVX---SD0805S020S1R0_AVX_SD0805S020S1R0_0
RTC_R_CAPACITOR: 15; ESP32_WROVER_EAGLE-LTSPICE_R0402
RTC_R_PINH1_1, RTC_R_PINH1_2: 10k; ESP32_WROVER_EAGLE-LTSPICE_R0402
SDC_C: 100nF; EAGLE-LTSPICE_C0402
SDC_SDC: 112A-TAAR-R03_ATTEND; 112ATAARR03ATTEND
SPIESD_D_1, SPIESD_D_2, SPIESD_D_3, SPIESD_D_4, SPIESD_D_5, SPIESD_D_6: PGB1010603MR; DIOC1608X36N
SPIESD_R_1, SPIESD_R_2, SPIESD_R_3, SPIESD_R_4, SPIESD_R_5, SPIESD_R_6: 10k; ESP32_WROVER_EAGLE-LTSPICE_R0402
TP1, TP2, TP3, TP4, TP5, TP6, TP7, TP8, TP9, TP10, TP11, TP12, TP13, TP14, TP15, TP16, TP17: TPTP20R; TP20R
USBC_C_USB_1: 100nF; EAGLE-LTSPICE_C0402
USBC_C_USB_2: 4.7uF; EAGLE-LTSPICE_C0402
USBC_R_USB_1, USBC_R_USB_2: 5k1; ESP32_WROVER_EAGLE-LTSPICE_R0402
USBC_USB: SAMACSYS_PARTS_USB4110-GF-A; SAMACSYS_PARTS_USB4110GFA
USBC_USBLC6-2SC6Y: USBLC6-2SC6Y; SOT95P280X145-6N
USBC_VARISTOR: ESP32C6_VARISTORCN1812; ESP32C6_VARISTOR_CT/CN1812
VOLREG_C_BAT_1, VOLREG_C_BAT_2: 4.7uF; EAGLE-LTSPICE_C0402
VOLREG_C_SUPER: 100uF; RCL_CT3528
VOLREG_D: ESP32_WROVER_AVX---SD0805S020S1R0_AVX_SD0805S020S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; ESP32_WROVER_AVX---SD0805S020S1R0_AVX_SD0805S020S1R0_0
VOLREG_MOSFET: 20V/4.2A/52mΩ/1.4W; ESP32_WROVER_SPARKFUN-DISCRETESEMI_SOT23-3
VOLREG_R: 100k; ESP32_WROVER_EAGLE-LTSPICE_R0402
VOLREG_XC6220A331MR-G: XC6220A331MR-G; SOT95P280X125-5N
VOLSPV_BD5229G-TR: BD5229G-TR; SOT95P280X125-5N
VOLSPV_BOOT_BUTTON: BUTTON_CUSYOMV1; MYBUTTON
VOLSPV_CHANGE_BUTTON: BUTTON_CUSYOMV1; MYBUTTON
VOLSPV_C_5: 1uF; EAGLE-LTSPICE_C0402
VOLSPV_C_6, VOLSPV_C_7: 100nF; EAGLE-LTSPICE_C0402
VOLSPV_C_DELAY: 100nF; EAGLE-LTSPICE_C0402
VOLSPV_RESET_BUTTON: BUTTON_CUSYOMV1; MYBUTTON
VOLSPV_R_BOOT: 10k; ESP32_WROVER_EAGLE-LTSPICE_R0402
VOLSPV_R_CHANGE: 10k; ESP32_WROVER_EAGLE-LTSPICE_R0402
VOLSPV_R_RESET: 10k; ESP32_WROVER_EAGLE-LTSPICE_R0402

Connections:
3V3: EPDPOW_Q.3 (D), EPDPOW_R_CL_1.2, ESP32.2 (3V3), ESP_R.2, FLASH_NOR.3 (!WP!(IO2)), FLASH_NOR.7 (!HOLD!/!RESET!(IO3)), FLASH_NOR.8 (VCC), QWIIC.2, RTC_COUNTER.2 (VCC), RTC_D.2 (ANODE), RTC_R_PINH1_1.2, RTC_R_PINH1_2.2, SDC_C.1, SDC_SDC.P4 (VDD), SPIESD_R_1.2, SPIESD_R_2.2, SPIESD_R_3.2, SPIESD_R_4.2, SPIESD_R_5.2, SPIESD_R_6.2, TP16.TP, VOLREG_C_BAT_2.1, VOLREG_C_SUPER.+, VOLREG_XC6220A331MR-G.5 (VOUT), VOLSPV_BD5229G-TR.2 (VDD), VOLSPV_R_BOOT.2, VOLSPV_R_CHANGE.2, VOLSPV_R_RESET.2
32KHZ: ESP32.9 (IO1), RTC_COUNTER.1 (32KHZ), RTC_R_PINH1_2.1
DN: USBC_USB.A7, USBC_USB.B7, USBC_USBLC6-2SC6Y.4 (I/O2_2)
DP: USBC_USB.A6, USBC_USB.B6, USBC_USBLC6-2SC6Y.6 (I/O1_2)
EPD_3V3: EPDC_C_2.1, EPDC_L.2, EPDH_C_3.2, EPDH_HEADER.15, EPDH_HEADER.16, EPDPOW_Q.2 (S), TP17.TP
EPD_3V3_C: EPDPOW_Q.1 (G), EPDPOW_R_CL_1.1, ESP32.18 (IO20), TP13.TP
EPD_BUSY: EPDH_HEADER.9, ESP32.26 (IO3), TP9.TP
EPD_CS: EPDH_HEADER.12, ESP32.11 (IO10), SPIESD_D_5.2, SPIESD_R_5.1, TP10.TP
EPD_DC: EPDH_HEADER.11, ESP32.5 (IO5), TP11.TP
EPD_RST: EPDH_HEADER.10, ESP32.21 (IO23), TP12.TP
FLASH_CS: ESP32.12 (IO11), FLASH_NOR.1 (!CS), SPIESD_D_4.2, SPIESD_R_4.1
GDR: EPDC_Q.1 (G), EPDC_R_2.2, EPDH_HEADER.2
GND: BCL_MAX17048G+T10.1 (CTG), BCL_MAX17048G+T10.4 (GND), BCL_MAX17048G+T10.6 (QSTRT), BCL_MAX17048G+T10.9 (EP), ENVSENS_BME680.1 (GND), ENVSENS_BME680.5 (SDO), ENVSENS_BME680.7 (GND), ENVSENS_C_1.2, ENVSENS_C_2.2, EPDC_C_2.2, EPDC_D_1.1 (K), EPDC_R_2.1, EPDH_C_1.1, EPDH_C_2.1, EPDH_C_3.1, EPDH_C_4.1, EPDH_C_5.1, EPDH_C_6.1, EPDH_C_7.1, EPDH_C_8.1, EPDH_C_9.1, EPDH_C_10.1, EPDH_HEADER.8, EPDH_HEADER.17, EPDH_HEADER.MP1, EPDH_HEADER.MP2, EPDTS_R.1, EPDTS_SJ.1, ESP32.1 (GND), ESP32.28 (GND), ESP32.29_1 (GND), ESP32.29_2 (GND), ESP32.29_3 (GND), ESP32.29_4 (GND), ESP32.29_5 (GND), ESP32.29_6 (GND), ESP32.29_7 (GND), ESP32.29_8 (GND), ESP32.29_9 (GND), FLASH_NOR.4 (GND), FLASH_NOR.9 (EXP), LPBCC_C_BAT_1.2, LPBCC_C_BAT_2.2, LPBCC_MCP73831.2 (VSS), LPBCC_R_BAT_2.1, QWIIC.1, RTC_C.2, RTC_COUNTER.13 (GND), RTC_C_SUPERCAP.2, SDC_C.2, SDC_SDC.G1 (GND_1), SDC_SDC.G2 (GND_2), SDC_SDC.G3 (GND_3), SDC_SDC.G4 (GND_4), SDC_SDC.P6 (VSS), SPIESD_D_1.1, SPIESD_D_2.1, SPIESD_D_3.1, SPIESD_D_4.1, SPIESD_D_5.1, SPIESD_D_6.1, TP4.TP, TP5.TP, USBC_C_USB_1.2, USBC_C_USB_2.2, USBC_R_USB_1.1, USBC_R_USB_2.2, USBC_USB.A1, USBC_USB.A12, USBC_USB.B1, USBC_USB.B12, USBC_USB.MP1, USBC_USB.MP2, USBC_USB.MP3, USBC_USB.MP4, USBC_USBLC6-2SC6Y.2 (GND), VOLREG_C_BAT_1.2, VOLREG_C_BAT_2.2, VOLREG_C_SUPER.-, VOLREG_R.1, VOLREG_XC6220A331MR-G.2 (VSS), VOLSPV_BD5229G-TR.3 (GND), VOLSPV_BOOT_BUTTON.1, VOLSPV_BOOT_BUTTON.2, VOLSPV_CHANGE_BUTTON.1, VOLSPV_CHANGE_BUTTON.2, VOLSPV_C_5.2, VOLSPV_C_6.2, VOLSPV_C_7.2, VOLSPV_C_DELAY.2, VOLSPV_RESET_BUTTON.1, VOLSPV_RESET_BUTTON.2
I2C_PW: ENVSENS_BME680.6 (VDDIO), ENVSENS_C_1.1, ENVSENS_C_2.1, ENVSENS_R_PINH_1.2, ENVSENS_R_PINH_2.2, ESP32.17 (IO19)
INT_RTC: ESP32.8 (IO0), RTC_COUNTER.3 (SQW/!INT), RTC_R_PINH1_1.1, TP15.TP
IO/BOOT: ESP32.15 (IO9), VOLSPV_BOOT_BUTTON.3, VOLSPV_BOOT_BUTTON.4, VOLSPV_C_6.1, VOLSPV_R_BOOT.1
IO/CHANGE: ESP32.23 (IO15), VOLSPV_CHANGE_BUTTON.3, VOLSPV_CHANGE_BUTTON.4, VOLSPV_C_7.1, VOLSPV_R_CHANGE.1
MISO: ESP32.27 (IO2), FLASH_NOR.2 (DO(IO1)), SDC_SDC.P7 (DAT0), SPIESD_D_1.2, SPIESD_R_1.1, TP6.TP
MOSI: EPDH_HEADER.14, ESP32.7 (IO7), FLASH_NOR.5 (DI(IO0)), SDC_SDC.P3 (CMD), SPIESD_D_2.2, SPIESD_R_2.1, TP7.TP
unnamed: VOLREG_C_BAT_1.1, VOLREG_D.1 (CATHODE), VOLREG_MOSFET.2 (S), VOLREG_XC6220A331MR-G.1 (VIN), VOLREG_XC6220A331MR-G.3 (CE)
unnamed: VOLSPV_BD5229G-TR.5 (CT), VOLSPV_C_DELAY.1
unnamed: LPBCC_MCP73831.1 (STAT), LPBCC_R_BAT_1.2
unnamed: LPBCC_CHG_LED.C, LPBCC_R_BAT_1.1
unnamed: ESP32.10 (IO8), ESP_R.1
unnamed: LPBCC_MCP73831.5 (PROG), LPBCC_R_BAT_2.2
unnamed: USBC_R_USB_2.1, USBC_USB.B5
unnamed: EPDH_C_10.2, EPDH_HEADER.24
unnamed: EPDC_C_1.1, EPDC_D_1.2 (A), EPDC_D_2.1 (K)
unnamed: EPDH_C_8.2, EPDH_HEADER.22
unnamed: ENVSENS_BME680.2 (CSB), ENVSENS_BME680.8 (VDD)
unnamed: RTC_D.1 (CATHODE), RTC_R_CAPACITOR.1
unnamed: EPDH_C_6.2, EPDH_HEADER.20
unnamed: EPDH_C_5.2, EPDH_HEADER.19
unnamed: USBC_R_USB_1.2, USBC_USB.A5
unnamed: EPDH_C_4.2, EPDH_HEADER.18
unnamed: EPDH_C_2.2, EPDH_HEADER.5
unnamed: EPDH_C_1.2, EPDH_HEADER.4
PREVGH: EPDC_D_3.1 (K), EPDH_C_7.2, EPDH_HEADER.21
PREVGL: EPDC_D_2.2 (A), EPDH_C_9.2, EPDH_HEADER.23
RESE: EPDC_Q.2 (S), EPDC_R_1.2, EPDH_HEADER.3
RESE': EPDC_R_1.1, EPDTS_R.2, EPDTS_SJ.2
RESET: ESP32.3 (EN), VOLSPV_BD5229G-TR.1 (VOUT), VOLSPV_C_5.1, VOLSPV_RESET_BUTTON.3, VOLSPV_RESET_BUTTON.4, VOLSPV_R_RESET.1
RTC_RST: ESP32.16 (IO18), RTC_COUNTER.4 (!RST)
RX: ESP32.24 (RXD0/GPIO17), TP2.TP
SCK: EPDH_HEADER.13, ESP32.6 (IO6), FLASH_NOR.6 (CLK), SDC_SDC.P5 (CLK), SPIESD_D_3.2, SPIESD_R_3.1, TP8.TP
SCL: BCL_MAX17048G+T10.7 (SCL), ENVSENS_BME680.4 (SCK), ENVSENS_R_PINH_1.1, ESP32.20 (IO22), QWIIC.4, RTC_COUNTER.16 (SCL)
SDA: BCL_MAX17048G+T10.8 (SDA), ENVSENS_BME680.3 (SDI), ENVSENS_R_PINH_2.1, ESP32.19 (IO21), QWIIC.3, RTC_COUNTER.15 (SDA)
SRC: EPDC_C_1.2, EPDC_D_3.2 (A), EPDC_L.1, EPDC_Q.3 (D)
SS_SD: ESP32.4 (IO4), SDC_SDC.P2 (CD/DAT3), SPIESD_D_6.2, SPIESD_R_6.1
TX: ESP32.25 (TXD0/GPIO16), TP1.TP
USB_D+: ESP32.14 (IO13), USBC_USBLC6-2SC6Y.1 (I/O1_1)
USB_D-: ESP32.13 (IO12), USBC_USBLC6-2SC6Y.3 (I/O2_1)
VBAT: BCL_MAX17048G+T10.2 (CELL), BCL_MAX17048G+T10.3 (VDD), LPBCC_C_BAT_2.1, LPBCC_MCP73831.3 (VBAT), TP3.TP, VOLREG_MOSFET.3 (D)
VBUS: LPBCC_CHG_LED.A, LPBCC_C_BAT_1.1, LPBCC_MCP73831.4 (VIN), TP14.TP, USBC_C_USB_1.1, USBC_C_USB_2.1, USBC_USBLC6-2SC6Y.5 (VBUS), USBC_VARISTOR.2, VOLREG_D.2 (ANODE), VOLREG_MOSFET.1 (G), VOLREG_R.2
VRTC: RTC_C.1, RTC_COUNTER.14 (VBAT), RTC_C_SUPERCAP.1, RTC_R_CAPACITOR.2
VUSB: USBC_USB.A4, USBC_USB.A9, USBC_USB.B4, USBC_USB.B9, USBC_VARISTOR.1

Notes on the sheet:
EPD Power
Voltage Supervisor
LDO Voltage Regulator
Li-Po Battery Charging Controller
Battery Charge Level
Microcontroller
Qwicc / Stemma QT
SPI ESD Protection Lines
Environmental Sensor BME688
RTC Module DS3231SN
USB C Connector & ESD Protection
External NOR Flash
SD Card
E-Paper Drive Circuit
E-Paper Display Type Selector
E-Paper Display Header

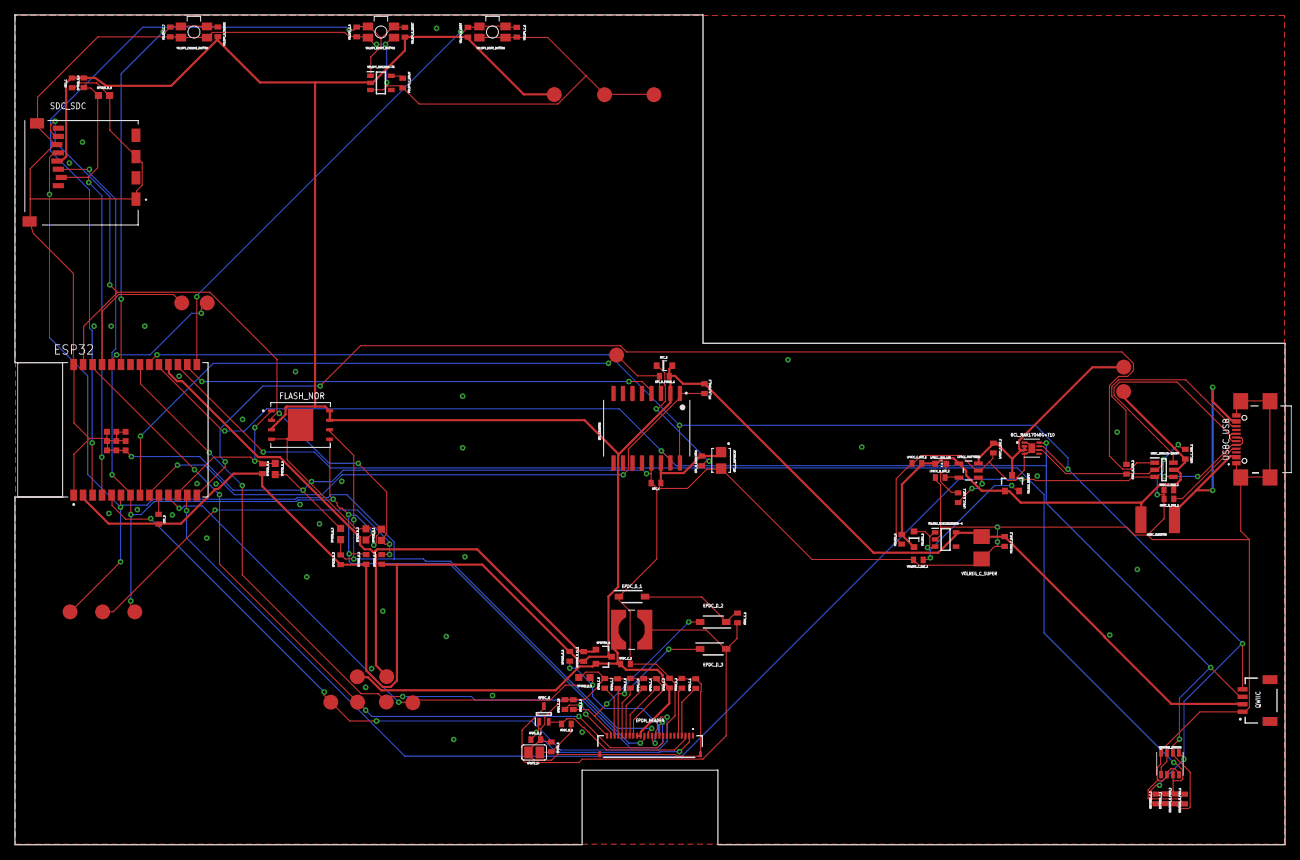
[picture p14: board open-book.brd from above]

Board: 2 copper layers, 170.2 x 111.2 mm, 103 parts (0 on the bottom side), 56 nets.

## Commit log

2025-04-07 Forgot to rename files
    [e_book_reader.brd, e_book_reader.sch]
2025-04-11 Fixed issue #4 by placing text on info layer
    [e_book_reader.sch]
2025-04-11 Fixed issue #1 by fixing VUSB connection
    [e_book_reader.brd]
2025-04-11 Fixed issue #2 by aligning components' names
    [e_book_reader.brd]
2025-04-14 Small fix
    [e_book_reader.brd, e_book_reader.sch, open-book.brd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]
2025-04-14 Another quick fix (Changed 3d wires and PCB extra names)
    [open-book.brd]
